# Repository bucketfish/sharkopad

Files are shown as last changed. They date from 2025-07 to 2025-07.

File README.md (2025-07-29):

# sharkopad!

sharkopad is a 6-key macropad with a rotary encoder & an oled screen. it will be your cutest & most favorite desktop buddy :)

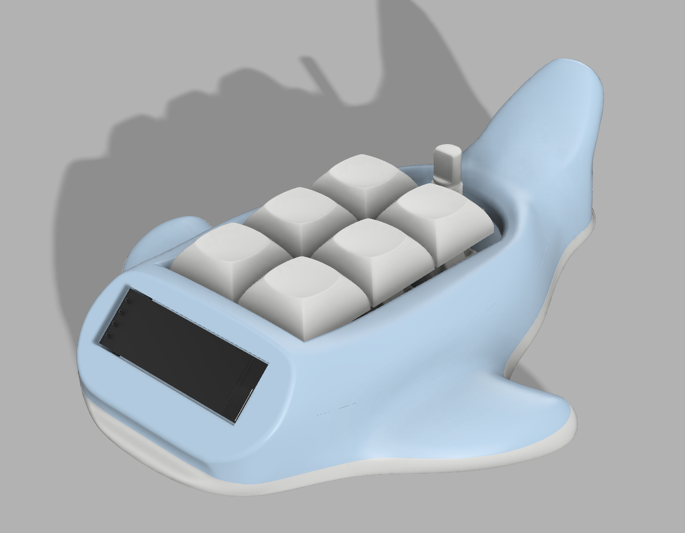
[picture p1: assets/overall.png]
sharkopad


features:

- 6 customisable keys
- backlights!!
- a rotary encoder
- a screen
- a yummy shark body

planned features:

- oled screen will show eyes and emotions
- rotary encoder changes layers so you can access more functions
- actually functioning backlights

these firmware changes are hard to test without the actual hardware so i will update it after i assemble it !!

# details

| schematic | pcb |
| ----- | ---- |
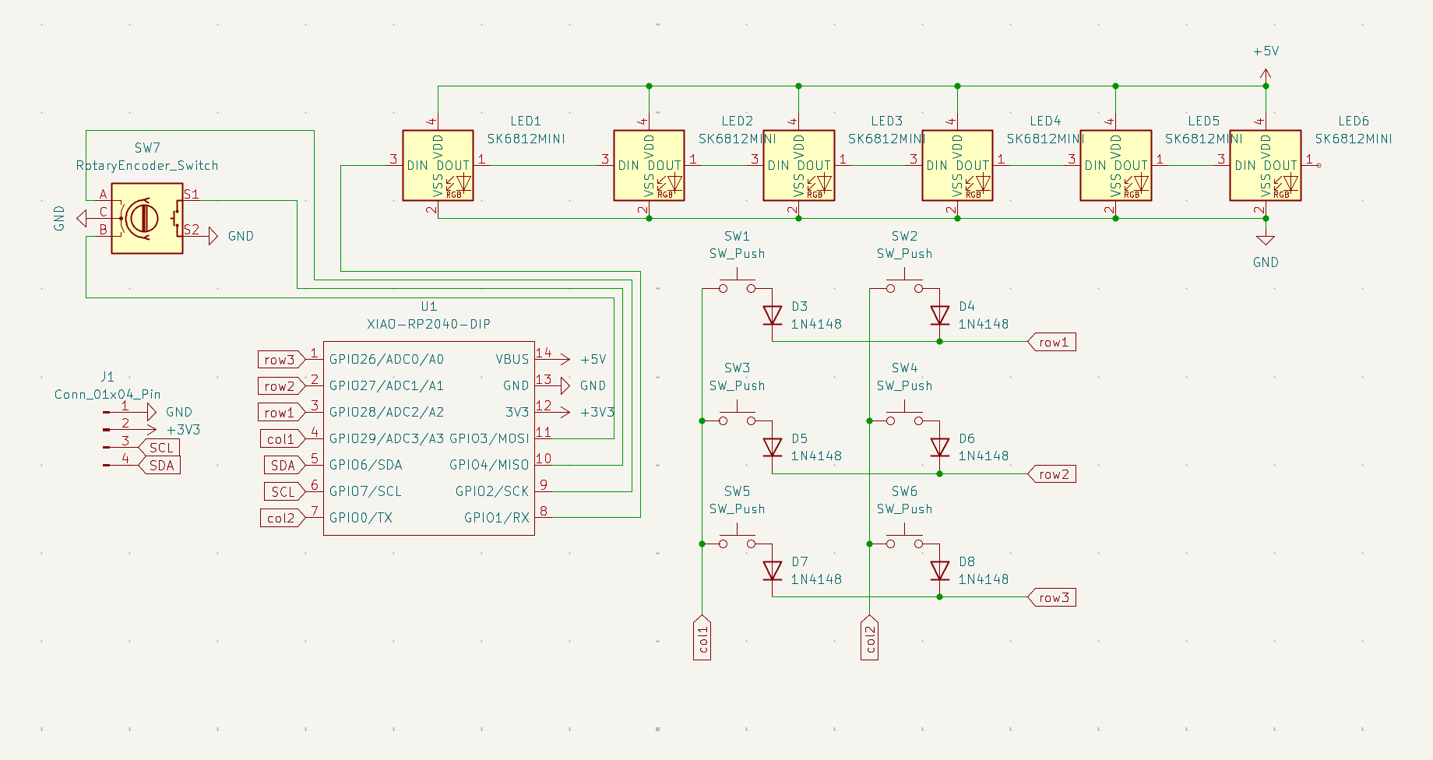
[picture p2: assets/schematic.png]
schematic
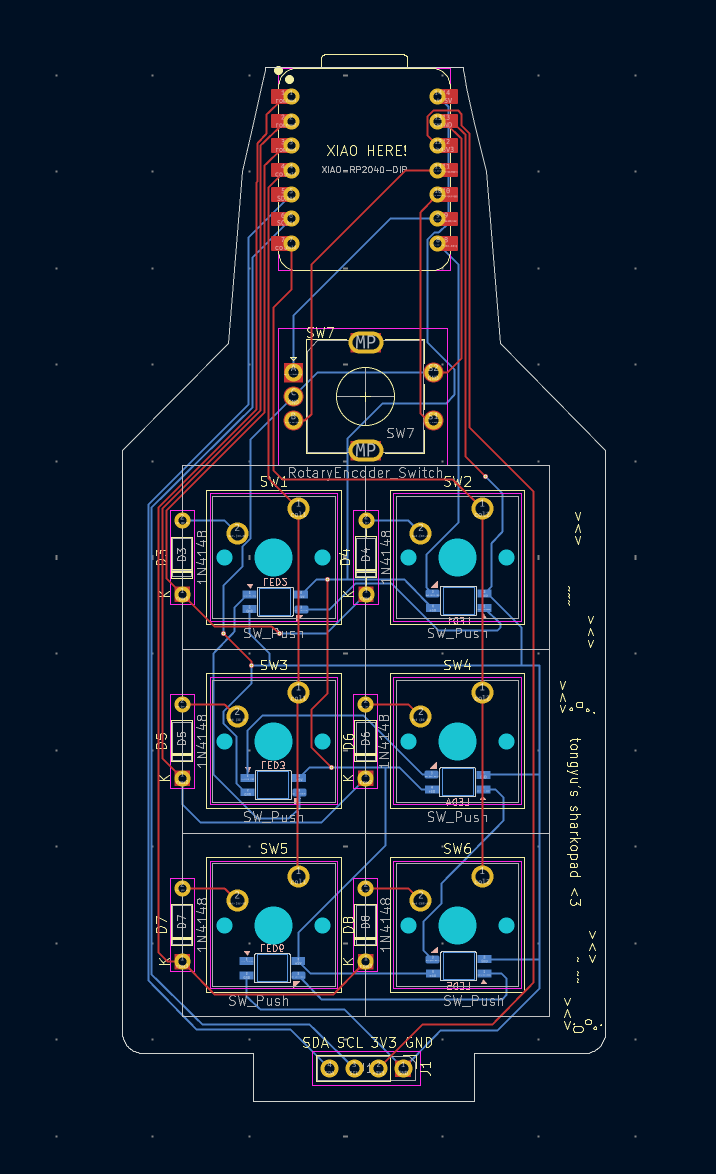
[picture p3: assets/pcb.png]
pcb
|  |  |

it is small and will be assembled with superglue 🙏

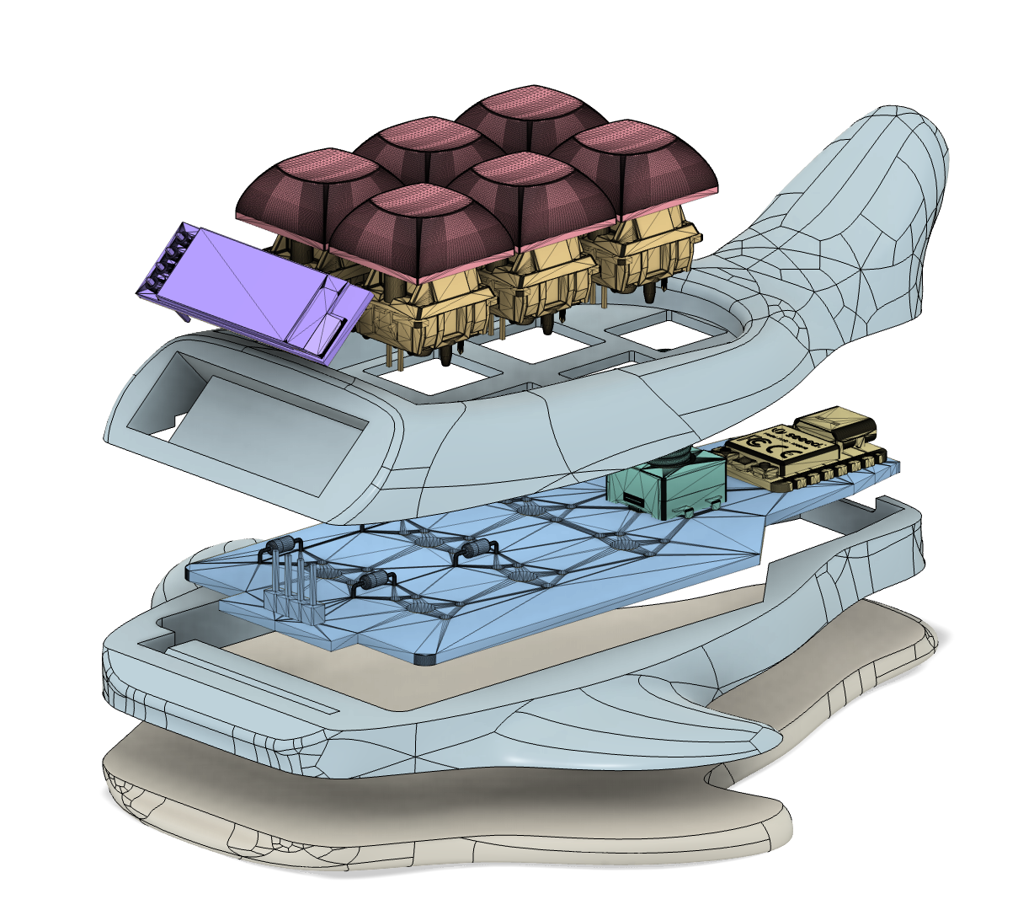
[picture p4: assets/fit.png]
assembly pic


# bom

| item | quantity |
| --- | --- |
| cherry mx switches | 6 |
| dsa keycap (ideally: jelly/translucent) | 6 |
| 128x32 oled display | 1 |
| ec11 rotary encoder | 1 |
| seeed xiao rp2040 | 1 |
| 1N4148 diode | 6 |
| SK6812 mini-e led | 6 |
| 1x4 pin header | 1 |
| short f/f 1x4 pin header connector | 1 |
| case (3 printed parts) | 1 |

& superglue...

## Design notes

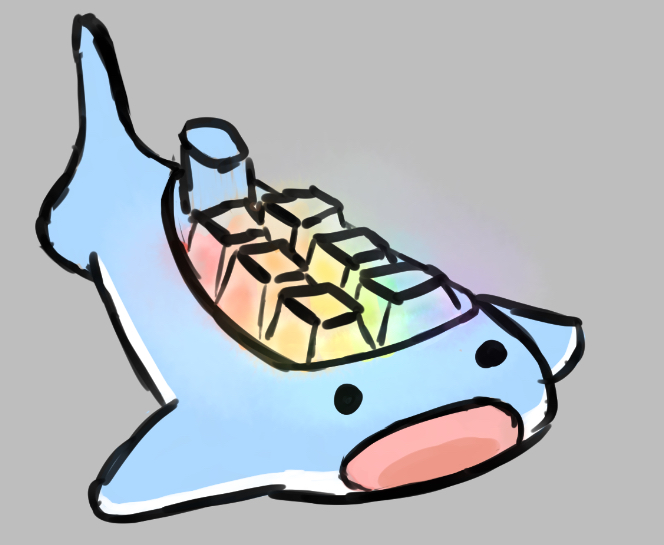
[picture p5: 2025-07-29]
assets/concept.jpeg

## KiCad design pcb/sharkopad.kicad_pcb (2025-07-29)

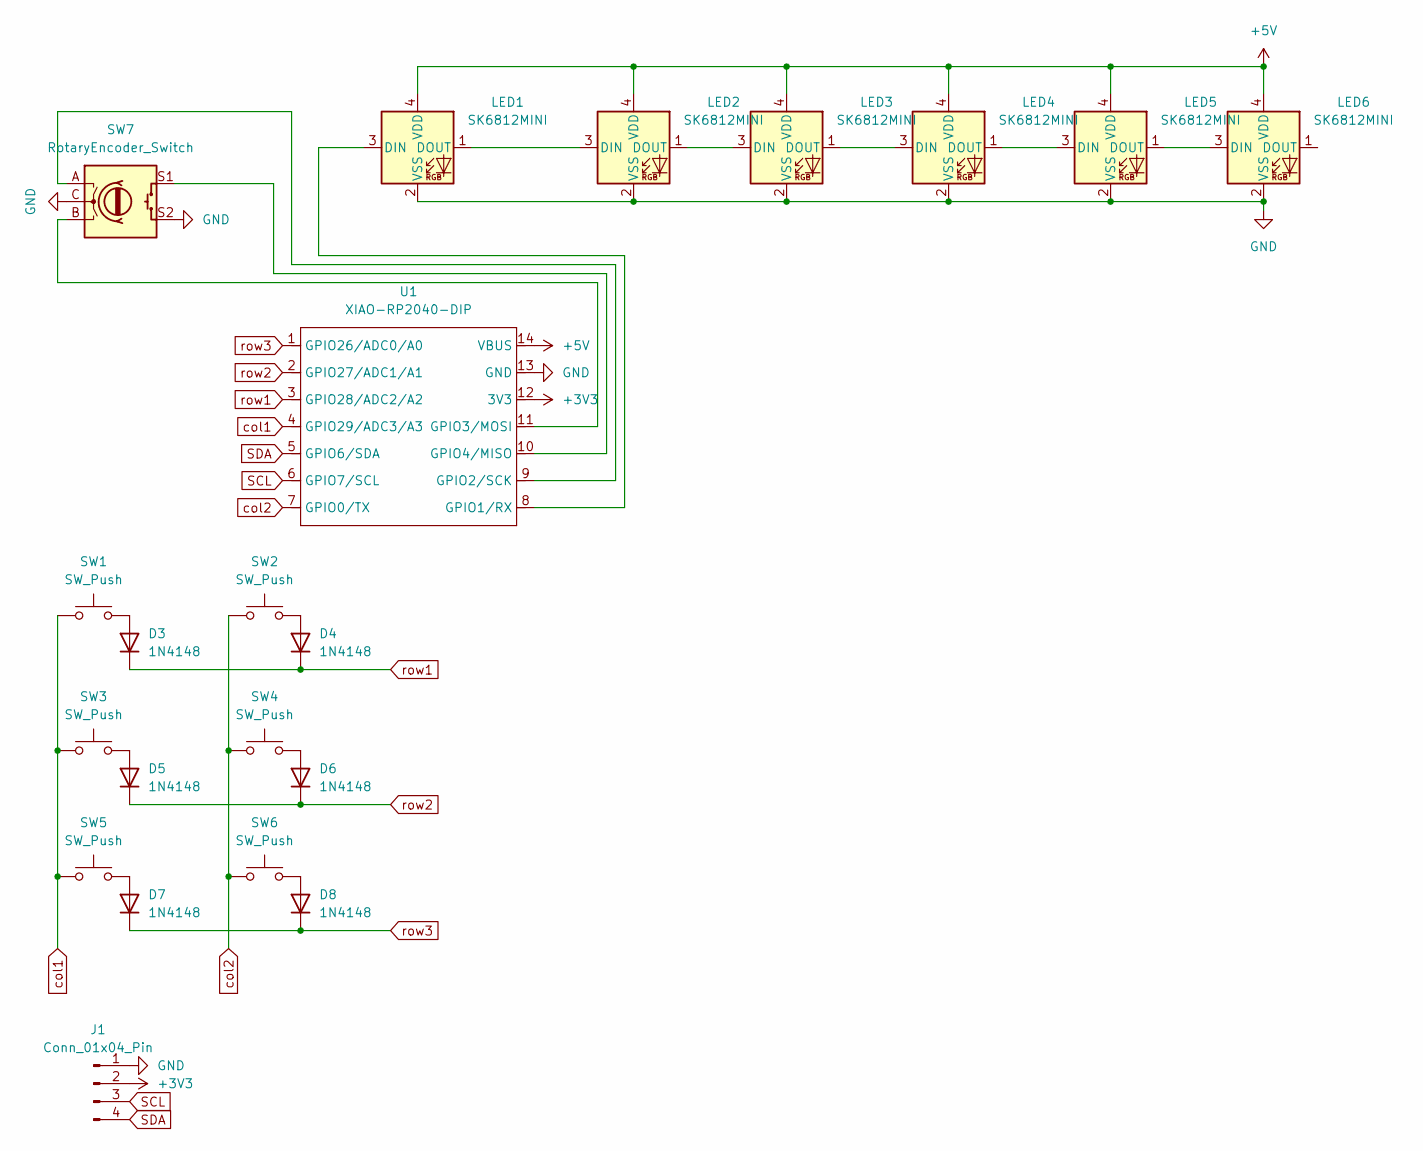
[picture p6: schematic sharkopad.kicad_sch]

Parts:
D3, D4, D5, D6, D7, D8: 1N4148; D_DO-35_SOD27_P7.62mm_Horizontal
J1: Conn_01x04_Pin; PinHeader_1x04_P2.54mm_Vertical
LED1, LED2, LED3, LED4, LED5, LED6: SK6812MINI; SK6812-MINI-E_REV
SW1, SW2, SW3, SW4, SW5, SW6: SW_Push; SW_Cherry_MX_1.00u_PCB
SW7: RotaryEncoder_Switch; RotaryEncoder_Alps_EC11E-Switch_Vertical_H20mm
U1: XIAO-RP2040-DIP

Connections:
+3V3: J1.2, U1.12 (3V3)
+5V: LED1.4 (VDD), LED2.4 (VDD), LED3.4 (VDD), LED4.4 (VDD), LED5.4 (VDD), LED6.4 (VDD), U1.14 (VBUS)
GND: J1.1, LED1.2 (VSS), LED2.2 (VSS), LED3.2 (VSS), LED4.2 (VSS), LED5.2 (VSS), LED6.2 (VSS), SW7.C, SW7.S2, U1.13 (GND)
unnamed: D3.2 (A), SW1.2
unnamed: D4.2 (A), SW2.2
unnamed: D5.2 (A), SW3.2
unnamed: D6.2 (A), SW4.2
unnamed: D7.2 (A), SW5.2
unnamed: D8.2 (A), SW6.2
unnamed: LED1.3 (DIN), U1.8 (GPIO1/RX)
unnamed: LED1.1 (DOUT), LED2.3 (DIN)
unnamed: LED2.1 (DOUT), LED3.3 (DIN)
unnamed: LED3.1 (DOUT), LED4.3 (DIN)
unnamed: LED4.1 (DOUT), LED5.3 (DIN)
unnamed: LED5.1 (DOUT), LED6.3 (DIN)
unnamed: SW7.A, U1.9 (GPIO2/SCK)
unnamed: SW7.B, U1.11 (GPIO3/MOSI)
unnamed: SW7.S1, U1.10 (GPIO4/MISO)
SCL: J1.3, U1.6 (GPIO7/SCL)
SDA: J1.4, U1.5 (GPIO6/SDA)
col1: SW1.1, SW3.1, SW5.1, U1.4 (GPIO29/ADC3/A3)
col2: SW2.1, SW4.1, SW6.1, U1.7 (GPIO0/TX)
row1: D3.1 (K), D4.1 (K), U1.3 (GPIO28/ADC2/A2)
row2: D5.1 (K), D6.1 (K), U1.2 (GPIO27/ADC1/A1)
row3: D7.1 (K), D8.1 (K), U1.1 (GPIO26/ADC0/A0)

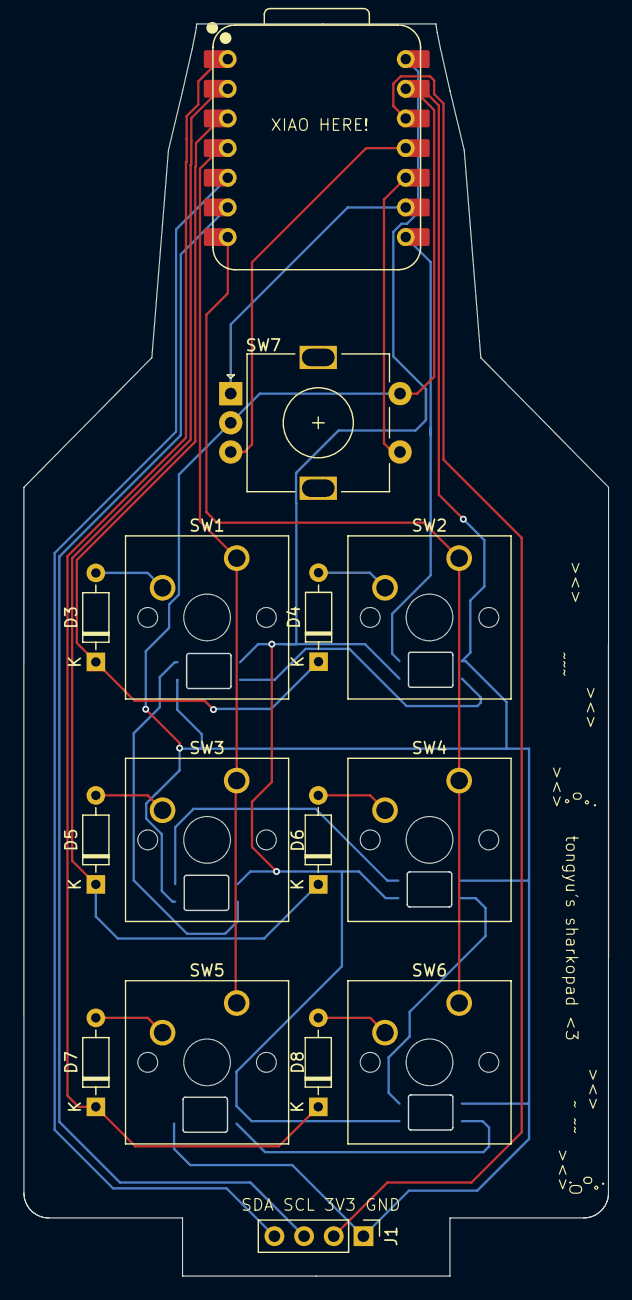
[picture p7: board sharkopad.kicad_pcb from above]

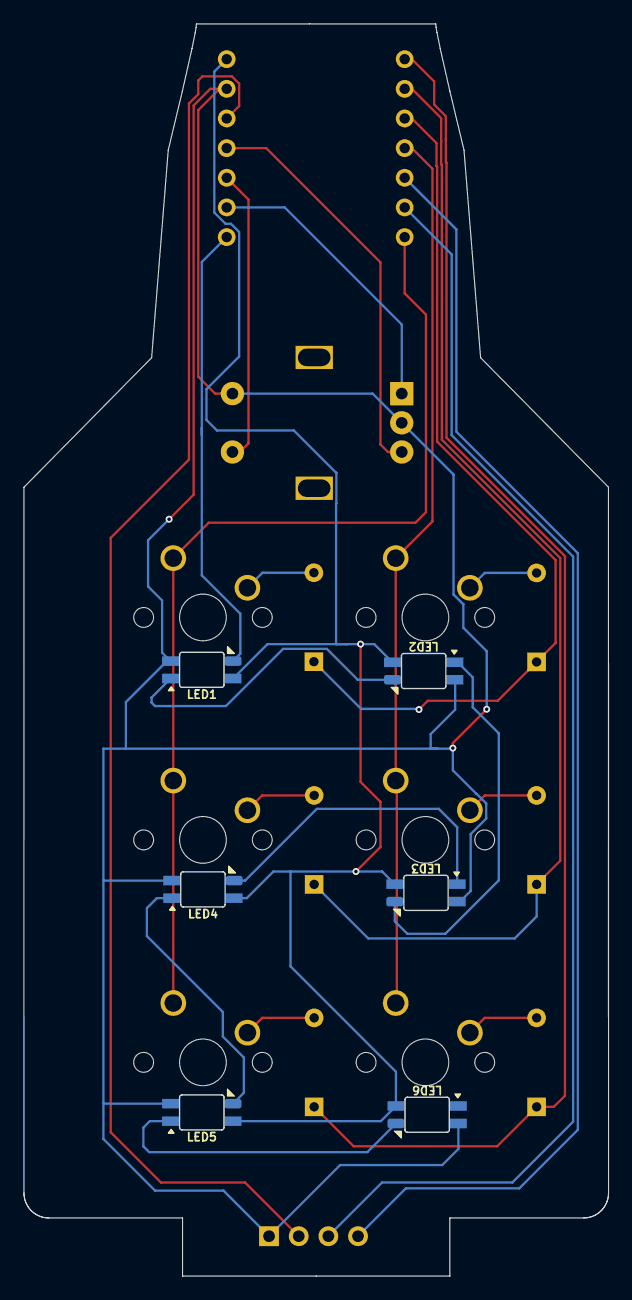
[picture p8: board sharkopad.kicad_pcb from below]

Board: 2 copper layers, 50.1 x 107.2 mm, 21 parts (6 on the bottom side), 25 nets.

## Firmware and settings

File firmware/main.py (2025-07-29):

import board
from kmk.kmk_keyboard import KMKKeyboard
from kmk.scanners import DiodeOrientation
from kmk.keys import KC

keyboard = KMKKeyboard()

keyboard.col_pins = (board.GP29, board.GP0)
keyboard.row_pins = (board.GP28, board.GP27, board.GP26)

keyboard.diode_orientation = DiodeOrientation.COL2ROW

keyboard.keymap = [[KC.LGUI(KC.C), KC.LGUI(KC.V), KC.LGUI(KC.X), KC.LGUI(KC.Z), KC.LGUI(KC.LSFT(KC.Z)), KC.LGUI(KC.Q)]]

if __name__ == '__main__':
    keyboard.go()
